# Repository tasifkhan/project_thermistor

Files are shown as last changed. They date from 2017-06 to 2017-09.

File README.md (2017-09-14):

## thermistor_array_driver

- Stream, visualize, and save 16 channel thermistor data using arduino due.
- The thermistor array is connected to the 32 pin .5 mm pitch FFC connector. Then, those connections goes to an analog switch, and to a bridge circuit.
- Switch address connections

| MUX Pins| Arduino Pins |
| :---:|:---:|
| EN |53 |
| A0 |51 |
| A1 |49 |
| A2 |47 |
| A3 |45 |

### directory setup

- /desktop_app/ ipython programs   and temperature and beta plot
  - 'temperature_mapping.ipynb' for real time temperature mapping
  - 'thermistor_array_plot_v1.ipynb' for thermistor temp and beta plots
- /desktop_app/data all raw data are saved here
- /firmware/ firmware for data streaming *use the latest version*
- /hardware/ hardware files

### notes

- 2017_09_13 added ipython real time temperature mapping and code for thermistor temp and beta plots
- 2017_08_27 checked both hardware and firmware, correctly outputting resistance values.

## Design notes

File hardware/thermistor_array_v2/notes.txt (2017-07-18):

resistors

.964 MOhm
.985 MOhm
1.014 MOhm

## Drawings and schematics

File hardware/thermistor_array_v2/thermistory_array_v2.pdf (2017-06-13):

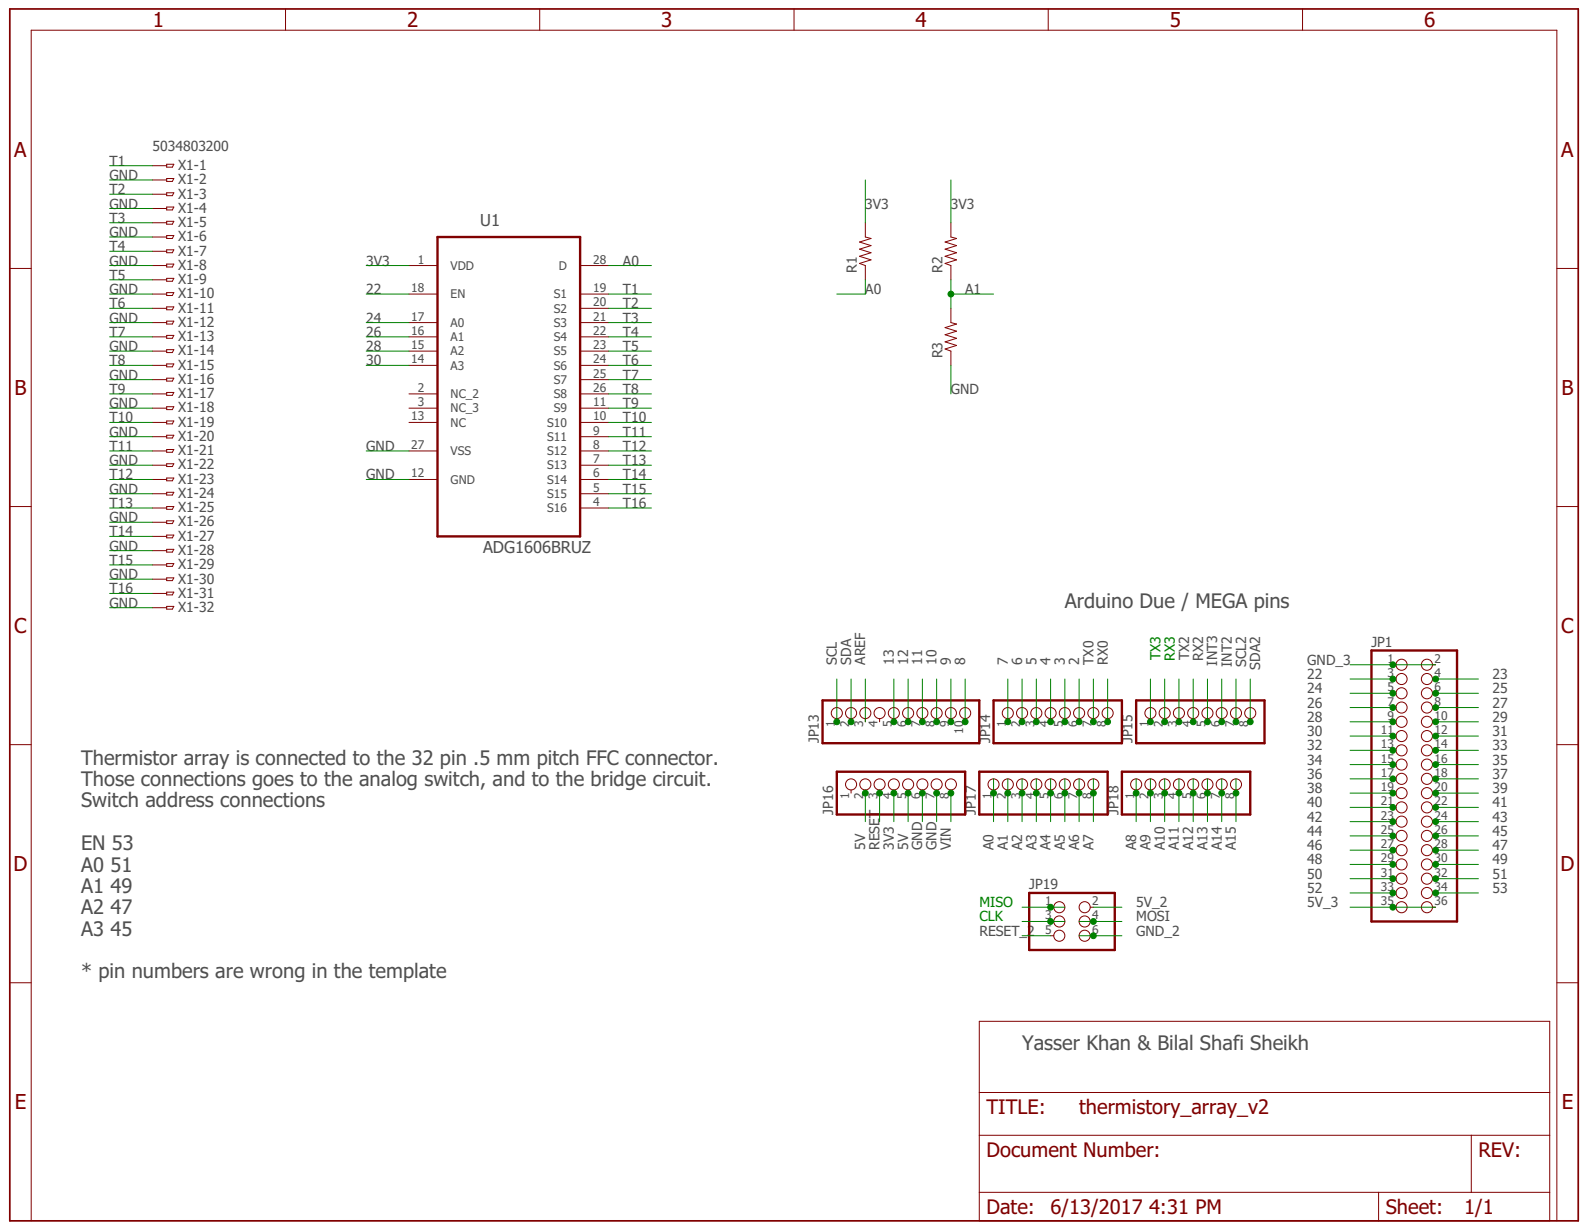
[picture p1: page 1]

Arduino Due / MEGA pins

Thermistor array is connected to the 32 pin .5 mm pitch FFC connector. Those connections goes to the analog switch, and to the bridge circuit. Switch address connections

* pin numbers are wrong in the template

Yasser Khan & Bilal Shafi Sheikh

Document Number: | REV:

Date: 6/13/2017 4:31 PM | Sheet: 1/1

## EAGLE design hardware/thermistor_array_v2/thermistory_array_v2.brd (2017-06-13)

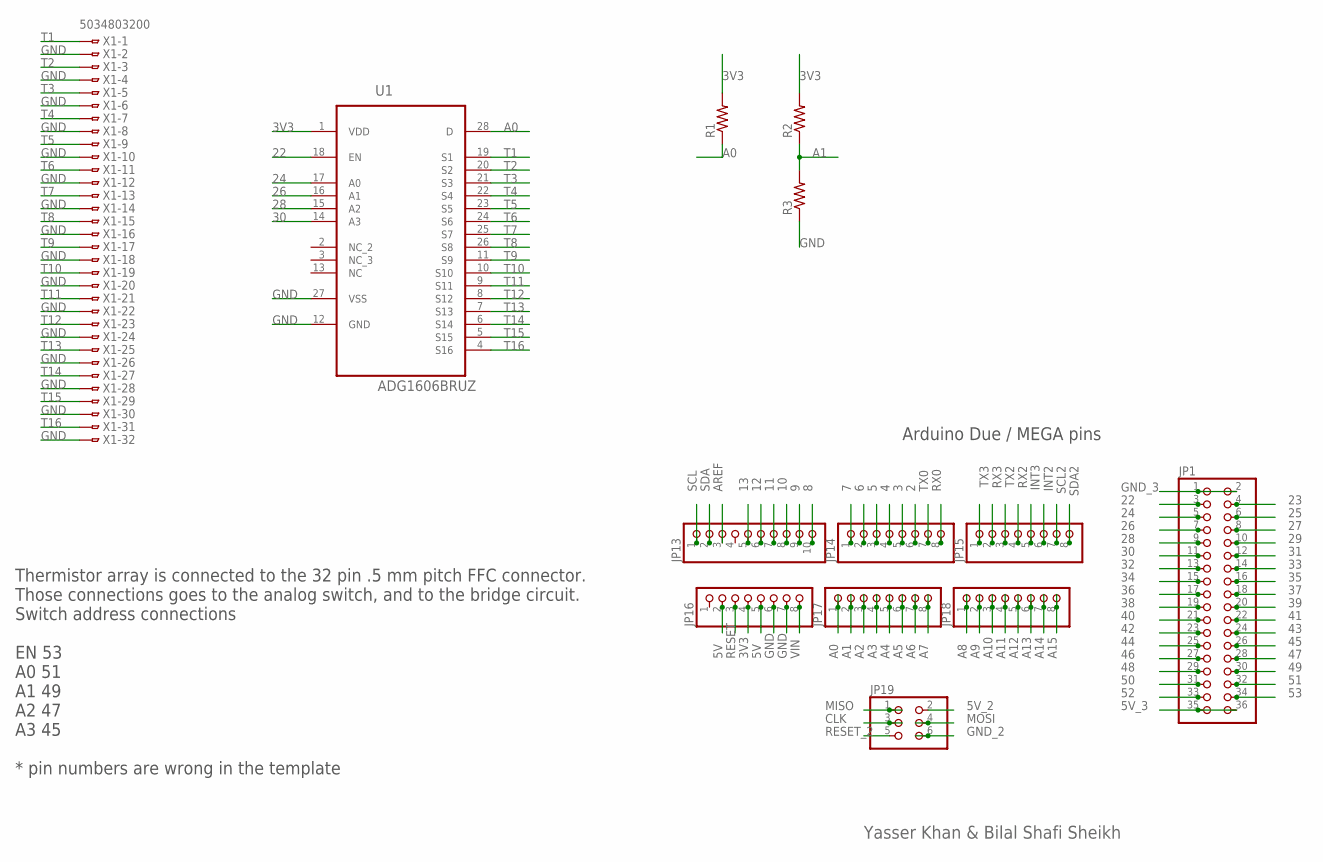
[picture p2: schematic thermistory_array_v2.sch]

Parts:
JP1: PINHD-2X18; 2X18
JP13: PINHD-1X10; 1X10
JP14, JP15, JP16, JP17, JP18: PINHD-1X8; 1X08
JP19: PINHD-2X3; 2X03
R1, R2, R3: RESISTORKIT; AXIAL-0.3-KIT
U1: ADG1606BRUZ; SOP65P640X120-28N
X1: 5034803200

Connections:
2: JP14.6
3: JP14.5
3V3: JP16.4, R1.P$2 (2), R2.P$2 (2), U1.1 (VDD)
4: JP14.4
5: JP14.3
5V: JP16.2, JP16.5
5V_2: JP19.2
5V_3: JP1.35, JP1.36
6: JP14.2
7: JP14.1
8: JP13.10
9: JP13.9
10: JP13.8
11: JP13.7
12: JP13.6
13: JP13.5
22: JP1.3, U1.18 (EN)
23: JP1.4
24: JP1.5, U1.17 (A0)
25: JP1.6
26: JP1.7, U1.16 (A1)
27: JP1.8
28: JP1.9, U1.15 (A2)
29: JP1.10
30: JP1.11, U1.14 (A3)
31: JP1.12
32: JP1.13
33: JP1.14
34: JP1.15
35: JP1.16
36: JP1.17
37: JP1.18
38: JP1.19
39: JP1.20
40: JP1.21
41: JP1.22
42: JP1.23
43: JP1.24
44: JP1.25
45: JP1.26
46: JP1.27
47: JP1.28
48: JP1.29
49: JP1.30
50: JP1.31
51: JP1.32
52: JP1.33
53: JP1.34
A0: JP17.1, R1.P$1 (1), U1.28 (D)
A1: JP17.2, R2.P$1 (1), R3.P$2 (2)
A2: JP17.3
A3: JP17.4
A4: JP17.5
A5: JP17.6
A6: JP17.7
A7: JP17.8
A8: JP18.1
A9: JP18.2
A10: JP18.3
A11: JP18.4
A12: JP18.5
A13: JP18.6
A14: JP18.7
A15: JP18.8
AREF: JP13.3
CLK: JP19.3
GND: JP16.6, JP16.7, R3.P$1 (1), U1.12 (GND), U1.27 (VSS), X1.2, X1.4, X1.6, X1.8, X1.10, X1.12, X1.14, X1.16, X1.18, X1.20, X1.22, X1.24, X1.26, X1.28, X1.30, X1.32
GND_2: JP19.6
GND_3: JP1.1, JP1.2
INT2: JP15.6
INT3: JP15.5
MISO: JP19.1
MOSI: JP19.4
RESET: JP16.3
RESET_2: JP19.5
RX0: JP14.8
RX2: JP15.4
RX3: JP15.2
SCL: JP13.1
SCL2: JP15.7
SDA: JP13.2
SDA2: JP15.8
T1: U1.19 (S1), X1.1
T2: U1.20 (S2), X1.3
T3: U1.21 (S3), X1.5
T4: U1.22 (S4), X1.7
T5: U1.23 (S5), X1.9
T6: U1.24 (S6), X1.11
T7: U1.25 (S7), X1.13
T8: U1.26 (S8), X1.15
T9: U1.11 (S9), X1.17
T10: U1.10 (S10), X1.19
T11: U1.9 (S11), X1.21
T12: U1.8 (S12), X1.23
T13: U1.7 (S13), X1.25
T14: U1.6 (S14), X1.27
T15: U1.5 (S15), X1.29
T16: U1.4 (S16), X1.31
TX0: JP14.7
TX2: JP15.3
TX3: JP15.1
VIN: JP16.8

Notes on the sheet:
Arduino Due / MEGA pins
Thermistor array is connected to the 32 pin .5 mm pitch FFC connector. Those connections goes to the analog switch, and to the bridge circuit. Switch address connections EN 53 A0 51 A1 49 A2 47 A3 45 * pin numbers are wrong in the template
Yasser Khan & Bilal Shafi Sheikh

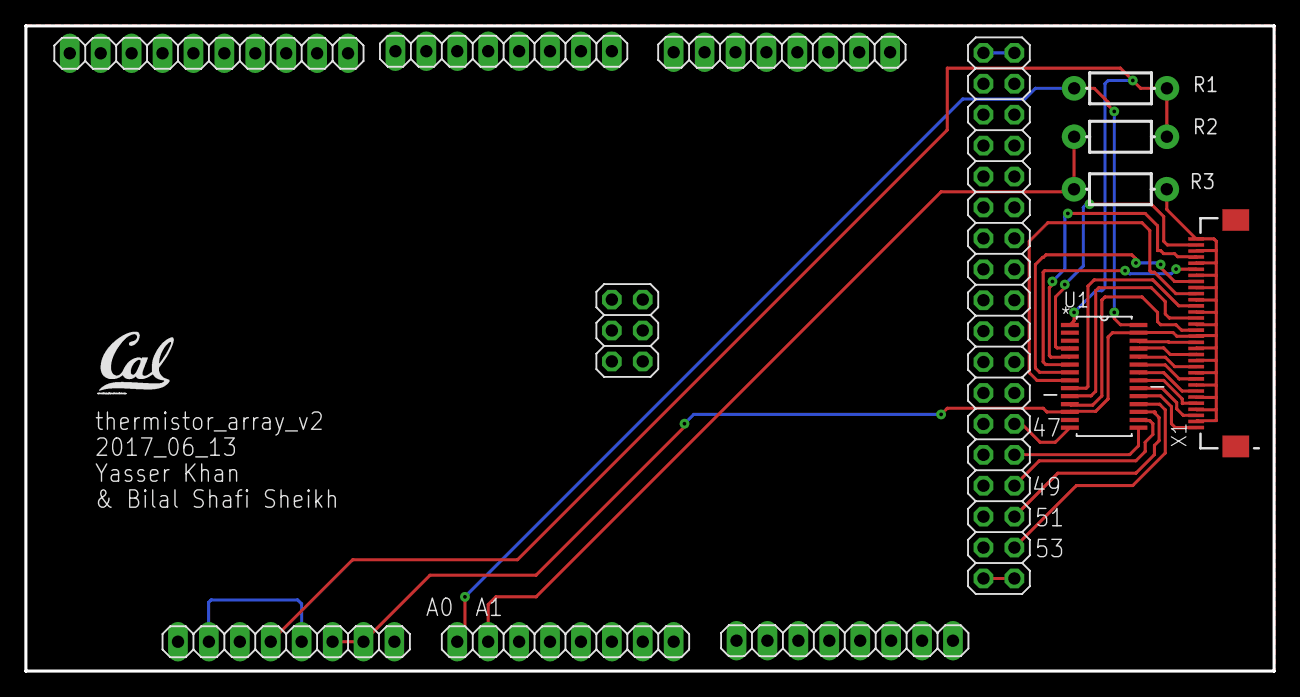
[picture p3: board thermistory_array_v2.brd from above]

Board: 2 copper layers, 102.5 x 53.0 mm, 13 parts (0 on the bottom side), 28 nets.

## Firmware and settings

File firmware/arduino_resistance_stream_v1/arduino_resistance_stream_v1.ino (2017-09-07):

// stream data from 16 channels 
// time pixel id resistance0 ref_resistance [MOhm]
// 2017_08_29 working version

unsigned long globalTime;
byte controlPins[] = {
  //A3 A2 A1 A0 EN 
  //45 47 49 51 53
  B00000001,
  B00000011,
  B00000101,
  B00000111,
  B00001001,
  B00001011,
  B00001101,
  B00001111,
  B00010001,
  B00010011,
  B00010101, 
  B00010111, 
  B00011001, 
  B00011011, 
  B00011101, 
  B00011111  }; 
 
// store adc values here   
float v0[] = {0,0,0,0,0,0,0,0,0,0,0,0,0,0,0,0}; // voltage reading 
float v1[] = {0,0,0,0,0,0,0,0,0,0,0,0,0,0,0,0}; // voltage reading               
int muxValues[] = {0,0,0,0,0,0,0,0,0,0,0,0,0,0,0,0}; // resistance 
float muxValues1[] = {0,0,0,0,0,0,0,0,0,0,0,0,0,0,0,0}; // resistance
float dummy[] = {0,0,0,0,0,0,0,0,0,0,0,0,0,0,0,0,};
char printTime[10];

String convert(int data) {
  float v0=3.3*(data/1024.0); // v0
  float res =((.964*v0)/(3.3)) / (1-(v0/3.3)); // (r0*(v0/3.3))/(1-(v0/3.3)) = rx
  return String(res, 4);
}

void setup()
{
  Serial.begin(115200);
  pinMode(45, OUTPUT); // A3
  pinMode(47, OUTPUT); // A2
  pinMode(49, OUTPUT); // A1
  pinMode(51, OUTPUT); // A0
  pinMode(53, OUTPUT); // EN
  pinMode(A0, INPUT);
  pinMode(A1, INPUT);
  
}
 
void displayData()
// dumps captured data from array to serial monitor
{
  
  for (int i = 0; i < 16; i++)
  {
    globalTime = int(millis() / 1000);
    char printTime[10];
    sprintf(printTime, "%06d", globalTime);
    Serial.print(printTime);
    Serial.print(' ');
    //Serial.print(i); // pixelID 
    Serial.print(' '); 
    Serial.print(convert(muxValues[i])); // resistance
    //Serial.print(' '); 
    //Serial.print(muxValues1[i]); // resistance
  }
  Serial.println('\r');  
}
 
void loop()
{
  
  
  for (int i = 0; i < 16; i++) // reading one channel at a time
  {
    // shift by 1 bit and writes the last bit to the pin
    digitalWrite(53, controlPins[i]>>0 & B00000001); //EN
    //Serial.print(controlPins[i]>>0 & B00000001);
    digitalWrite(51, controlPins[i]>>1 & B00000001); //A0
    //Serial.print(controlPins[i]>>1 & B00000001);
    digitalWrite(49, controlPins[i]>>2 & B00000001); //A1
    //Serial.print(controlPins[i]>>2 & B00000001);
    digitalWrite(47, controlPins[i]>>3 & B00000001); //A2
    //Serial.print(controlPins[i]>>3 & B00000001);
    digitalWrite(45, controlPins[i]>>4 & B00000001); //A3
    //Serial.println(controlPins[i]>>4 & B00000001);

    // dummy reads otherwise the adc goes all over the places - v0
    for (int j = 0; j < 5; j++){
      dummy[j]= analogRead(A0);
      delay(10);
    }
    //v0[i]=3.3*(analogRead(A0)/1024.0); // v0
    //muxValues[i]=((.964*v0[i])/(3.3)) / (1-(v0[i]/3.3)); // (r0*(v0/3.3))/(1-(v0/3.3)) = rx
    muxValues[i] = analogRead(A0);
    delay(10);

    // dummy reads otherwise the adc goes all over the places - v1
    for (int j = 0; j < 5; j++){
      dummy[j]=analogRead(A1);
      delay(10);
    }
    v1[i]=3.3*(analogRead(A1)/1024.0); // read the vlaue on that pin and store in array
    muxValues1[i]=((.985*v1[i])/(3.3)) / (1-(v1[i]/3.3));
    delay(50);
  }
 
  // display captured data
  
  displayData();
  delay(10); 
}

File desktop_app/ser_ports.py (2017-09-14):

import sys
import glob
import serial


def serial_ports():
    """ Lists serial port names

        :raises EnvironmentError:
            On unsupported or unknown platforms
        :returns:
            A list of the serial ports available on the system
    """
    if sys.platform.startswith('win'):
        ports = ['COM%s' % (i + 1) for i in range(256)]
    elif sys.platform.startswith('linux') or sys.platform.startswith('cygwin'):
        # this excludes your current terminal "/dev/tty"
        ports = glob.glob('/dev/tty[A-Za-z]*')
    elif sys.platform.startswith('darwin'):
        ports = glob.glob('/dev/tty.*')
    else:
        raise EnvironmentError('Unsupported platform')

    result = []
    for port in ports:
        try:
            s = serial.Serial(port)
            s.close()
            result.append(port)
        except (OSError, serial.SerialException):
            pass
    return result


if __name__ == '__main__':
    serial_ports()

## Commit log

2017-06-13 Initial commit.
    [thermistory_array_v2.brd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]
2017-07-18 new arduino stream
2017-09-14 added code for mapping and plotting
    [2016_05_11_project_thermistor_data.xlsx, 2016_05_17_project_thermistor_data.xlsx, 2016_05_23_project_thermistor_data.xlsx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]

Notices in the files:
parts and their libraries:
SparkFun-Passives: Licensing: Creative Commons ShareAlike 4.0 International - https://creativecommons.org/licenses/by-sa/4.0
